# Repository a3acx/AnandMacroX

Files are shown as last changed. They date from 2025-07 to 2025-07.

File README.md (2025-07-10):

# AnandMacroX
## What is this?
This project is esentially a MacroPad designed with 12 Cherry MX Switches (3 rows and 4 columns) with 4 EC11 Rotary Encoders located under the the switches. This MacroPad also includes an 128x64 OLED display which could be used to display anything from the time and date to performnace statistics of your computer.

## Why did I make this?
When I was playing a video game, I realized that it would be nice if i had some shortcuts to perform certain actions faster. I looked around on the internet and found many suitable options. However, there was a major issue. All of the options that I considered were over $200! That is when I decided that I would try to make my own. And what you see here is that result.

## Pictures

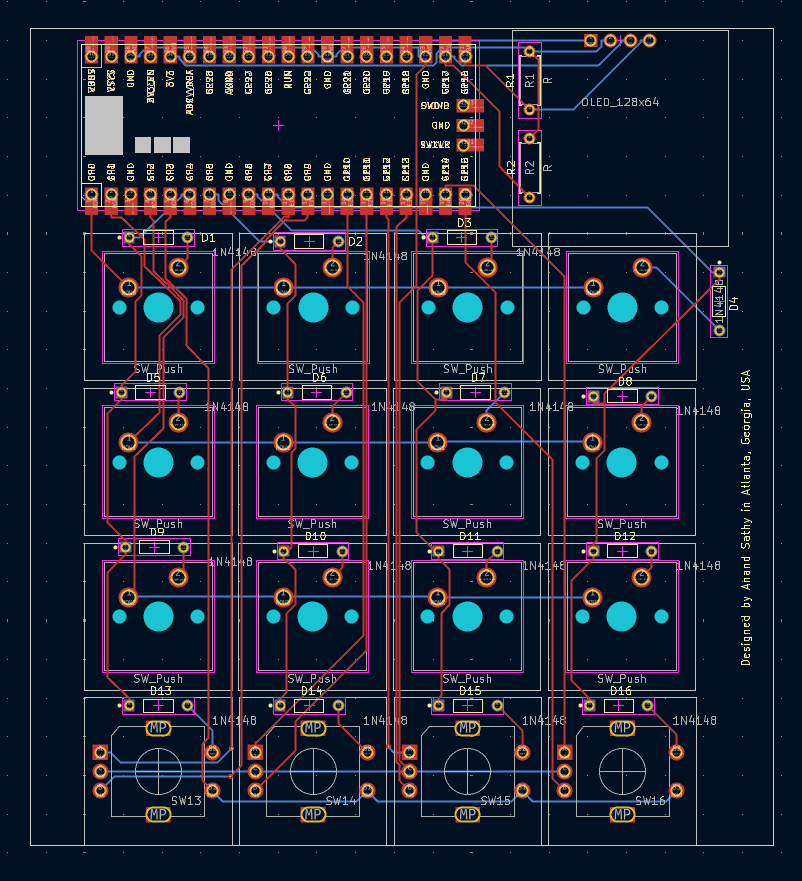
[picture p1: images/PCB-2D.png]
2 Dimensional View of the PCB

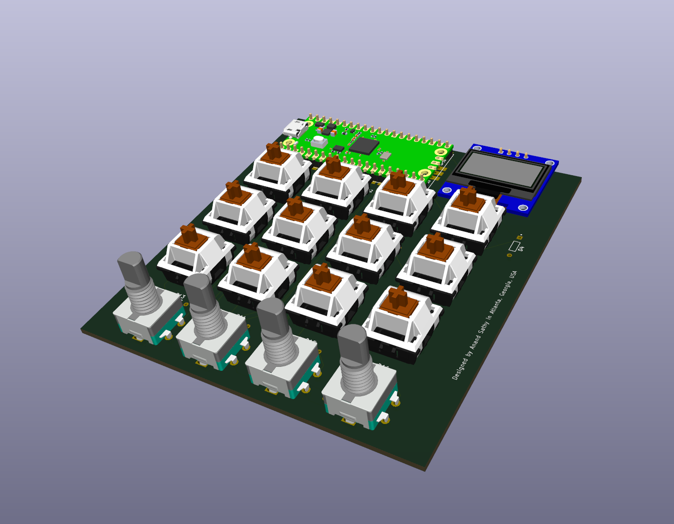
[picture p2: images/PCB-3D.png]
3 Dimensional View of the PCB

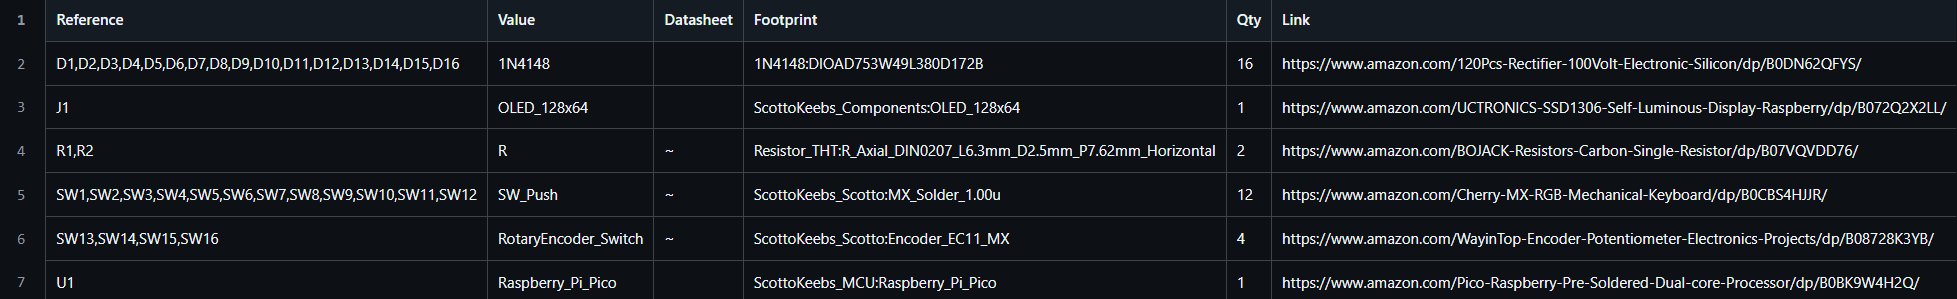
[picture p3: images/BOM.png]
Screenshot of Bill of Materials


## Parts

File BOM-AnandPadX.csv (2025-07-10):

Reference | Value | Datasheet | Footprint | Qty | Link
D1,D2,D3,D4,D5,D6,D7,D8,D9,D10,D11,D12,D13,D14,D15,D16 | 1N4148 |  | 1N4148:DIOAD753W49L380D172B | 16 | https://www.amazon.com/120Pcs-Rectifier-100Volt-Electronic-Silicon/dp/B0DN62QFYS/
J1 | OLED_128x64 |  | ScottoKeebs_Components:OLED_128x64 | 1 | https://www.amazon.com/UCTRONICS-SSD1306-Self-Luminous-Display-Raspberry/dp/B072Q2X2LL/
R1,R2 | R | ~ | Resistor_THT:R_Axial_DIN0207_L6.3mm_D2.5mm_P7.62mm_Horizontal | 2 | https://www.amazon.com/BOJACK-Resistors-Carbon-Single-Resistor/dp/B07VQVDD76/
SW1,SW2,SW3,SW4,SW5,SW6,SW7,SW8,SW9,SW10,SW11,SW12 | SW_Push | ~ | ScottoKeebs_Scotto:MX_Solder_1.00u | 12 | https://www.amazon.com/Cherry-MX-RGB-Mechanical-Keyboard/dp/B0CBS4HJJR/
SW13,SW14,SW15,SW16 | RotaryEncoder_Switch | ~ | ScottoKeebs_Scotto:Encoder_EC11_MX | 4 | https://www.amazon.com/WayinTop-Encoder-Potentiometer-Electronics-Projects/dp/B08728K3YB/
U1 | Raspberry_Pi_Pico |  | ScottoKeebs_MCU:Raspberry_Pi_Pico | 1 | https://www.amazon.com/Pico-Raspberry-Pre-Soldered-Dual-core-Processor/dp/B0BK9W4H2Q/

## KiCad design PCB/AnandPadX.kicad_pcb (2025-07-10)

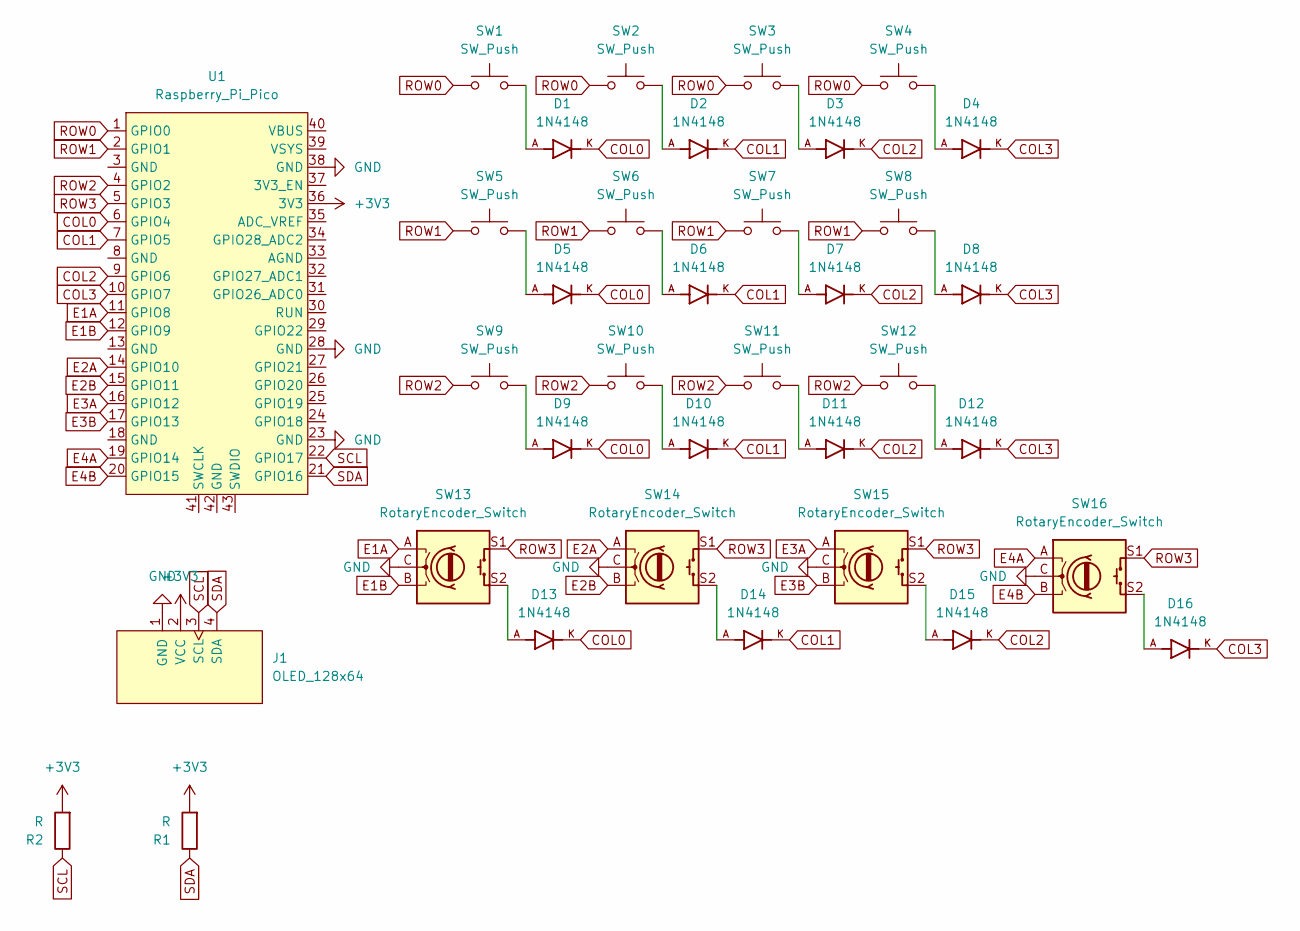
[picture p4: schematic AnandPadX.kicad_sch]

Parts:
D1, D2, D3, D4, D5, D6, D7, D8, D9, D10, D11, D12, D13, D14, D15, D16: 1N4148; DIOAD753W49L380D172B; PARTREV 5
J1: OLED_128x64
R1, R2: R; R_Axial_DIN0207_L6.3mm_D2.5mm_P7.62mm_Horizontal
SW1, SW2, SW3, SW4, SW5, SW6, SW7, SW8, SW9, SW10, SW11, SW12: SW_Push; MX_Solder_1.00u
SW13, SW14, SW15, SW16: RotaryEncoder_Switch; Encoder_EC11_MX
U1: Raspberry_Pi_Pico

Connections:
+3V3: J1.2 (VCC), R1.2, R2.2, U1.36 (3V3)
COL0: D1.K, D5.K, D9.K, D13.K, U1.6 (GPIO4)
COL1: D2.K, D6.K, D10.K, D14.K, U1.7 (GPIO5)
COL2: D3.K, D7.K, D11.K, D15.K, U1.9 (GPIO6)
COL3: D4.K, D8.K, D12.K, D16.K, U1.10 (GPIO7)
E1A: SW13.A, U1.11 (GPIO8)
E1B: SW13.B, U1.12 (GPIO9)
E2A: SW14.A, U1.14 (GPIO10)
E2B: SW14.B, U1.15 (GPIO11)
E3A: SW15.A, U1.16 (GPIO12)
E3B: SW15.B, U1.17 (GPIO13)
E4A: SW16.A, U1.19 (GPIO14)
E4B: SW16.B, U1.20 (GPIO15)
GND: J1.1 (GND), SW13.C, SW14.C, SW15.C, SW16.C, U1.23 (GND), U1.28 (GND), U1.38 (GND)
unnamed: D1.A, SW1.2
unnamed: D2.A, SW2.2
unnamed: D3.A, SW3.2
unnamed: D4.A, SW4.2
unnamed: D5.A, SW5.2
unnamed: D6.A, SW6.2
unnamed: D7.A, SW7.2
unnamed: D8.A, SW8.2
unnamed: D9.A, SW9.2
unnamed: D10.A, SW10.2
unnamed: D11.A, SW11.2
unnamed: D12.A, SW12.2
unnamed: D13.A, SW13.S2
unnamed: D14.A, SW14.S2
unnamed: D15.A, SW15.S2
unnamed: D16.A, SW16.S2
ROW0: SW1.1, SW2.1, SW3.1, SW4.1, U1.1 (GPIO0)
ROW1: SW5.1, SW6.1, SW7.1, SW8.1, U1.2 (GPIO1)
ROW2: SW9.1, SW10.1, SW11.1, SW12.1, U1.4 (GPIO2)
ROW3: SW13.S1, SW14.S1, SW15.S1, SW16.S1, U1.5 (GPIO3)
SCL: J1.3 (SCL), R2.1, U1.22 (GPIO17)
SDA: J1.4 (SDA), R1.1, U1.21 (GPIO16)

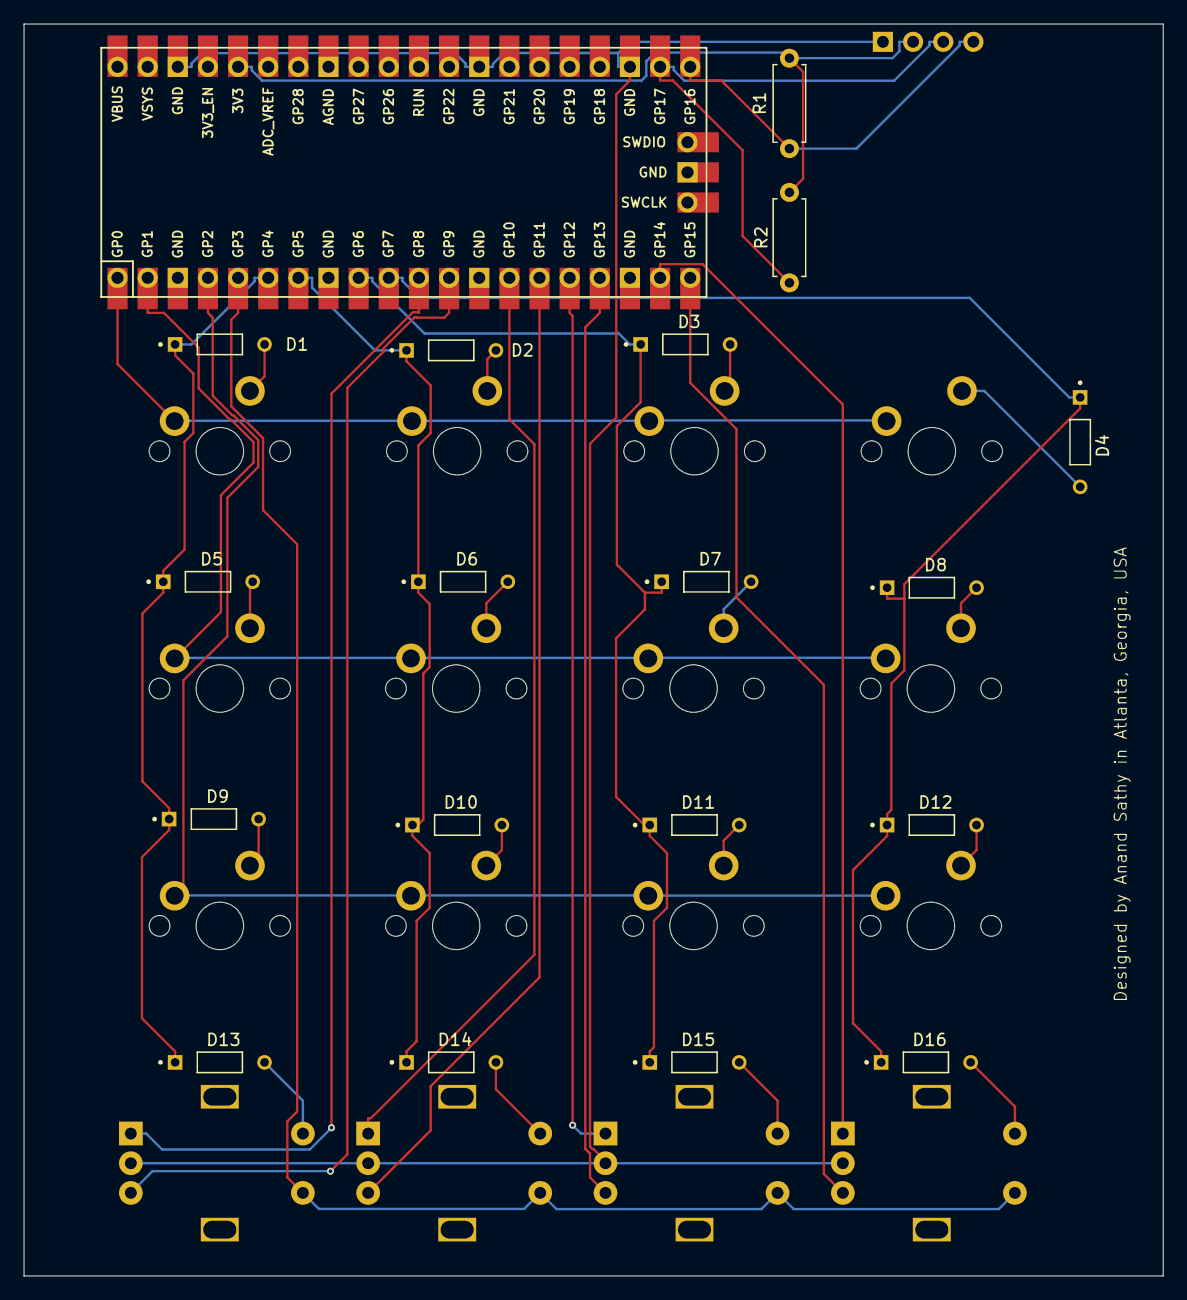
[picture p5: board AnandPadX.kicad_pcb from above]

Board: 2 copper layers, 96.0 x 105.5 mm, 36 parts (0 on the bottom side), 36 nets.

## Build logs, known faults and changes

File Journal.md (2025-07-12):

---
title: "AnandPadX"
author: "Anand Sathy (a3acx)"
description: "This is a leveled up MacroPad"
created_at: "2025-06-25"
---
# My Journal
## TOTAL TIME: 
## June 25th, 2025
Today, I chose all of the parts that I needed/wanted for my leveled up macropad. I spent two hours on this.
## June 27th, 2025
Today, I worked on the schematic using all the parts previously picked. I spent 3 hours on this.


## July 10th, 2025
Today, i worked on placing everything on the PCB side of things. The snap grid was malfunctioning :( but after I updated Kicad to Version 9.0, it got much better! I also routed the PCB and spent 4 hours working on this.


## July 11th, 2025
Today, I redesigned my PCB multiple times to try to get it down to 100mmx100mm. I did this successfully. I also worked on the bottom portion of the case for my MacroPad. This took a total of 4 hours.





## July 12th, 2025
Today, I worked on the top portion of my case. I also properly centered the EC11s on on the PCB. This took a total of 2 hours.
